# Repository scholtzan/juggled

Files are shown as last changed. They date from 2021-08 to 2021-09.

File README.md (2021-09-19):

# juggled - LED Juggling Ball

> Work in progress

This repository contains all the files and instructions for 3D printing and creating LED juggling balls that can be controlled via Bluetooth.

_Watch a demo of the juggling balls on Youtube:_

Youtube video (https://www.youtube.com/watch?v=KDMFEAo71LQ)

## Required Materials

The following components are required to build a single juggling ball:

* ESP32
 DEVKIT V1
	* This development board has an onboard Bluetooth module, will control the LEDs and collect data from the accelerometer
* Lithium 
Battery
 3.7V
	* The battery will power the ESP32 and all other components
* Li-lon Battery
 Charger
	* This component will ensure that the Lithium battery can be recharged via micro USB
* Accelerometer
	* For collecting data on whether the juggling ball has been thrown or caught
* 2x RGB LEDs
	* To make the juggling ball glow
* Resistors
	* 1x 1kΩ
	* 1x 4.7kΩ
	* Used to read the battery charge via the ESP32
* Switch
	* To turn the juggling ball on and off
* Capacitor (1 to 100uF)
	* Required in order to ensure ESP32 gets flashed without having to push any buttons on the microcontroller
* Wire
	* For connecting all the components
* Heat Shrink Tubes
	* For insulating soldered wires
* Soldering Iron + Solder
	* All the components need to be soldered together
* Transparent TPU
	* For printing the outer shell
	* Soft and flexible material will ensure that components and inner core are protected when juggling balls are dropped
* Clear PLA+
	* For inner core that will help to keep electronics in place
* Hot Glue
	* For glueing outer shell onto inner core and for fixating electronics

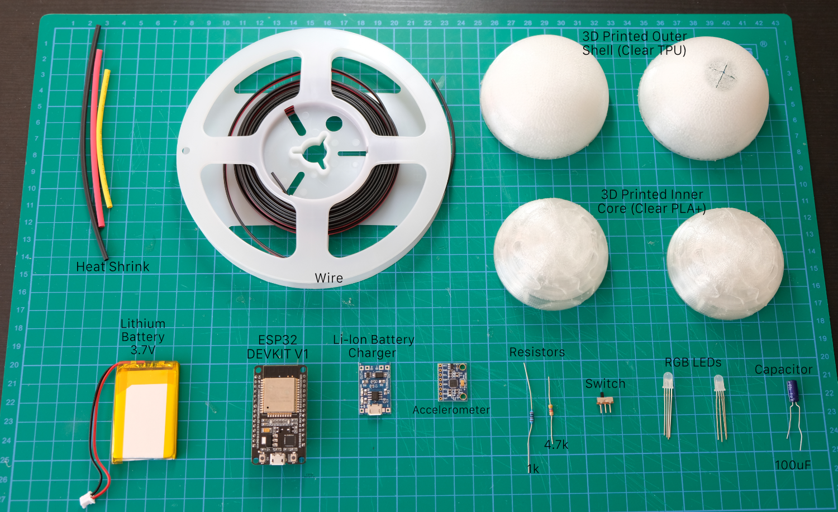
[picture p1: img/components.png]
Components


## 3D Printed Shell

The juggling ball consists of an inner core and an outer shell. The models can be found in the `models/` folder.
All files are also available on Thingiverse: https://www.thingiverse.com/thing:4969010

For printing the inner core which will hold all the components in place, use a transparent material. PLA+ or PETG are more sturdy, but PLA should also work. I have used the following parameters for printing the inner core with transparent PLA+:

* Temperature: 200C
* Build Plate Temperature: 60C
* Layer Height: 0.2mm
* Infill Density: 5%
* Infill Pattern: Gyroid
* Print Speed: 80mm/s
* Generate Support: yes
	* Support density: 5%

The inner core and all components are protected by an outer shell printed with transparent TPU. The outer shell consists of two parts - a back and a front. The front will allow access to the switch and USB ports. I have used the following parameters for printing the shell:

* Temperature: 220C
* Build Plate Temperature: 75C
* Layer Height: 0.2mm
	* Adaptive Layers: yes
		* Maximum Variation: 0.1mm
		* Variation Step Size: 0.1mm
* Flow: 105%
* Infill Density: 30%
* Infill Pattern: Gyroid
* Print Speed: 20mm/s
* Retraction Distance: 3mm
* Generate Support: no

## Circuit Overview

The following diagram shows how the circuit for the LED juggling ball works:

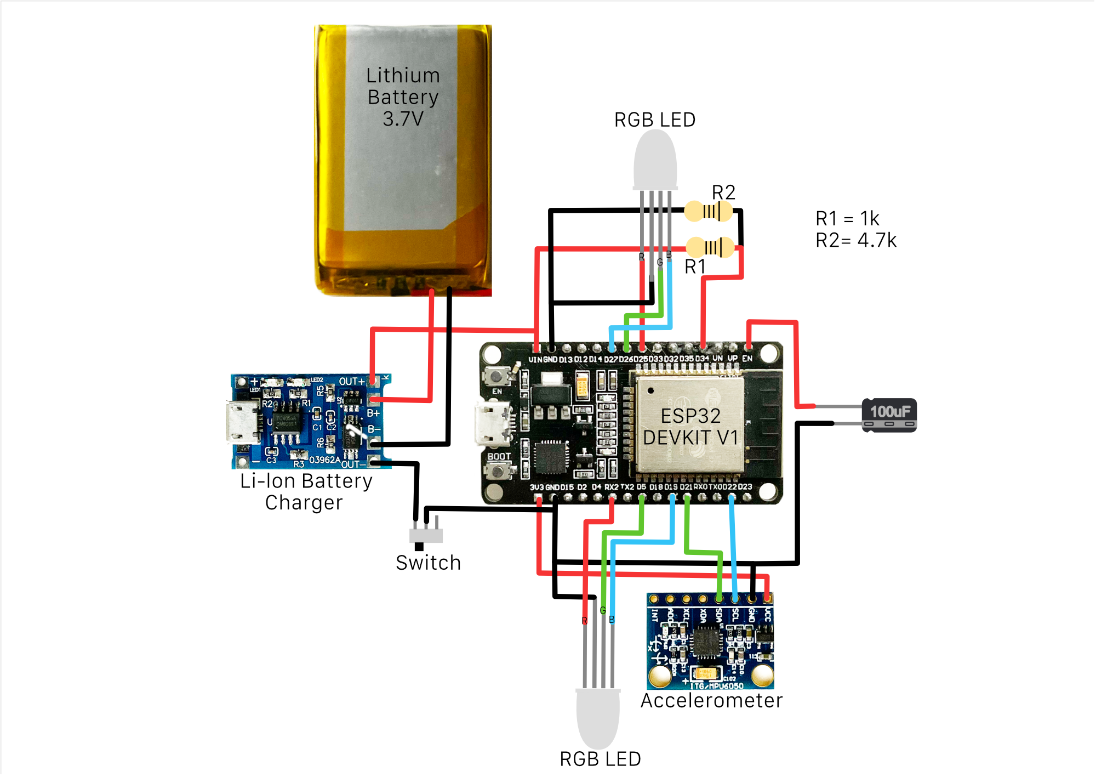
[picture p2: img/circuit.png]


1. The lithium battery outputs 3.7V when fully charged and can power the ESP32 DEVKIT
2. The lithium battery is connected to a charger module which allows the battery to be charged via micro USB
3. The two RGB LEDs are directly connected to the ESP32
4. The two resistors connect the lithium battery directly to one pin of the ESP32. This connection will be used to determine how much charge the battery has left
5. The accelerometer is connected to and powered by the ESP32
6. The capacitor is connected to EN to ensure the ESP32 gets flashed without having to press any buttons

## Assembly

For assembling and soldering the electronic components together, follow the circuit overview diagram above. As space is very limited inside the juggling ball, the components need to be sandwiched together:

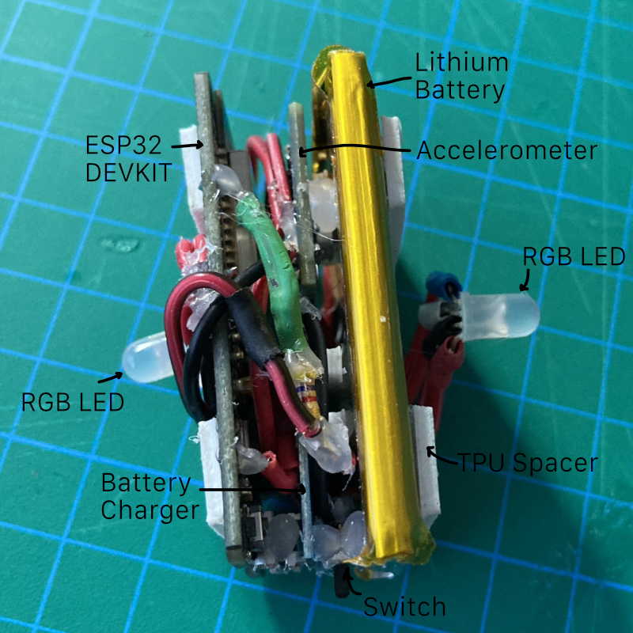
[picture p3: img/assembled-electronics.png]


The switch, battery charging module and accelerometer are put in between the lithium battery and ESP32 DEVKIT. The LEDs will be located on the battery and the ESP32. To ensure components stay in place, I printed some additional spacers using TPU and used some hot glue. The assembled bock of electronic components should not exceed 22mm in height as it would otherwise not fit into the inner core of the juggling ball. Ensure that the switch and the USB slots a properly aligned with the opening.

Once all the electronic components have been assembled, they can be place inside the inner core of the juggling ball. Each side of the inner core has holes for the LEDs to fit through. The two pieces for the inner core need to be glue together, either by using hot glue or Gorilla glue. Next, glue the two pieces of the outer shell onto the inner core using hot glue. Make sure that the piece of shell with the opening to access the switch and USB ports is properly aligned.

## Juggling Ball Software

The code running on the ESP32 of each juggling ball is located in the `ball-code` directory. The code can be [loaded on to the ESP32](https://www.etechnophiles.com/how-to-install-program-an-esp32-with-arduino-ide-for-the-first-time/) using [Arduino IDE](https://www.arduino.cc/en/software).

The code running on the juggling balls will allow devices to connect to it via BLE and send commands to change the color or get information about the battery voltage.

### Protocol

For specifying the LED behaviour the juggling ball can process messages that follow the following format:

```
set;<action>;<arg>|<action>;<arg>|...
```

The juggling ball behaviour can be defined in multiple steps. Each step is separated by `|`. For each step an `action` is specified, some `action`s require additional `arg`uments to be specified, such as `setcolor` expects the RGB values for the two LEDs. Once an action has been completed, the juggling ball will move on to process the next defined step. Once the last step defined have been processed, the juggling ball will again go back to the first step.

Supported `action`s are: `wait`, `thrown`, `caught` and `setcolor`. `arg` is required when `wait` and `setcolor` is used. For `wait` the millisecons how long the ball will wait until processing the next step needs to be specified. `setcolor` requires the `<r>,<g>,<b>;<r>,<g>,<b>` values of the two LEDs.

For setting the color of one LED to red and the other to blue the message would look as follows:

```
set;setcolor;255,0,0;0,0,255
```  

To have the juggling ball switch between red and green every second the message would look like:

```
set;wait;1000|setcolor;255,0,0;0,0,255|wait;1000|setcolor;0,0,255;0,0,255
```

To change the color to blue when a ball is in the air and to red when it is caught:

```
set;caught|setcolor;255,0,0;255,0,0|thrown|setcolor;0,0,255;0,0,255
```

All messages need to be converted to HEX. So for the first example the following message would need to be sent to the juggling ball in order for it to correctly interpret it: 

```
7365743b636f6c6f723b3b3235352c302c303b302c302c323535
```

## iOS Application

The code for the iOS application is in the `app/` directory, which makes connecting juggling balls, defining behaviours and collecting statistics very easy. The application is not part of the App Store, instead it can be loaded on to iOS devices via Xcode.

### Usage

New juggling balls can be connected to via the "+" button. A list of available juggling balls will appear, balls can get selected and will appear under "Home".

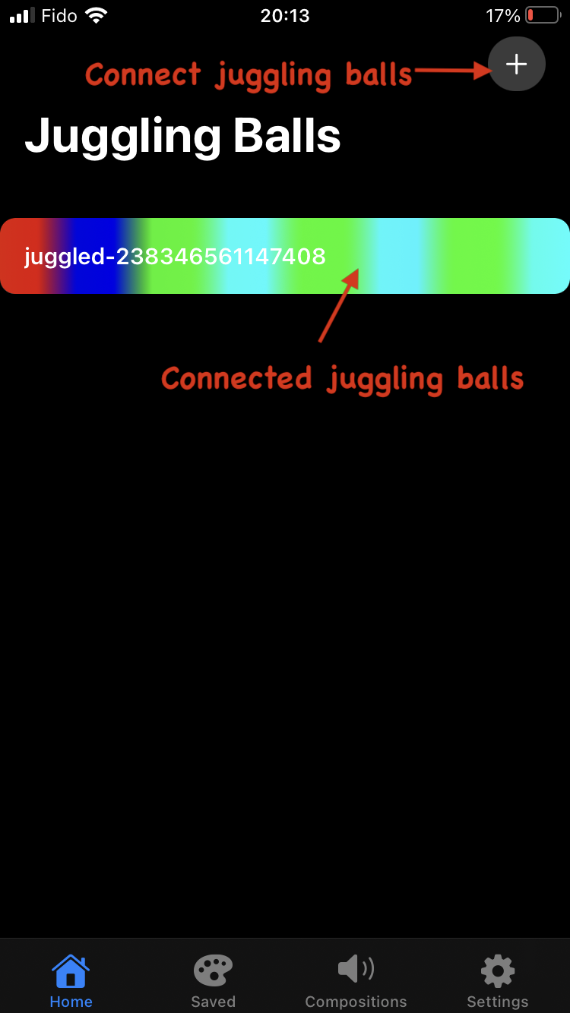
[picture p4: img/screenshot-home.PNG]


Clicking on a juggling ball entry will show the configuration of the juggling ball. The juggling ball routine can be edited by deleting steps or adding new steps via the "+ Add Step" button.

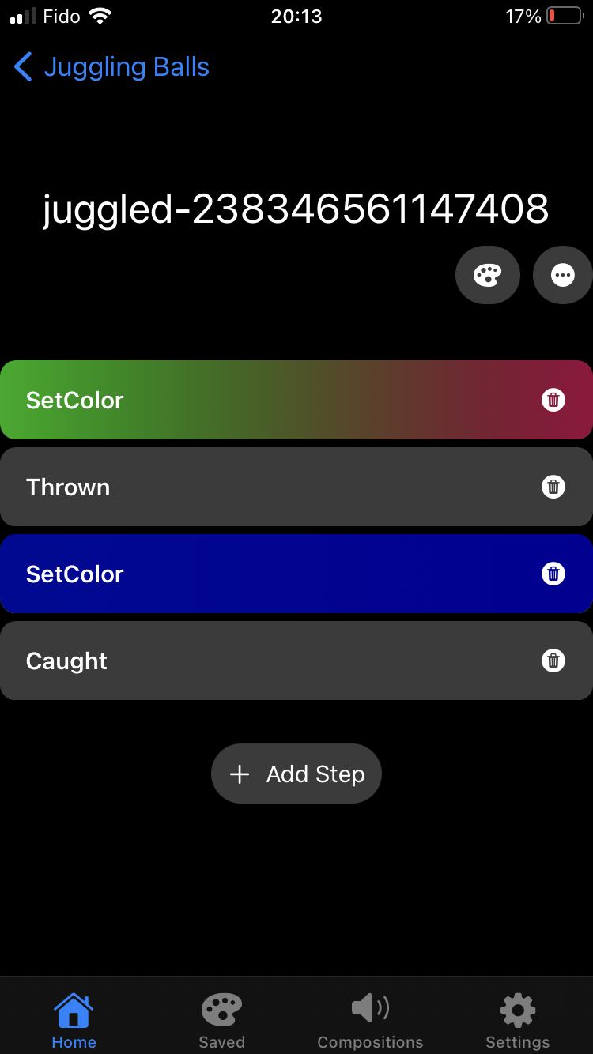
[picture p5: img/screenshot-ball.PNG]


When adding a new step, `Set Color` is selected by default. This action allows to set the color for each LED.

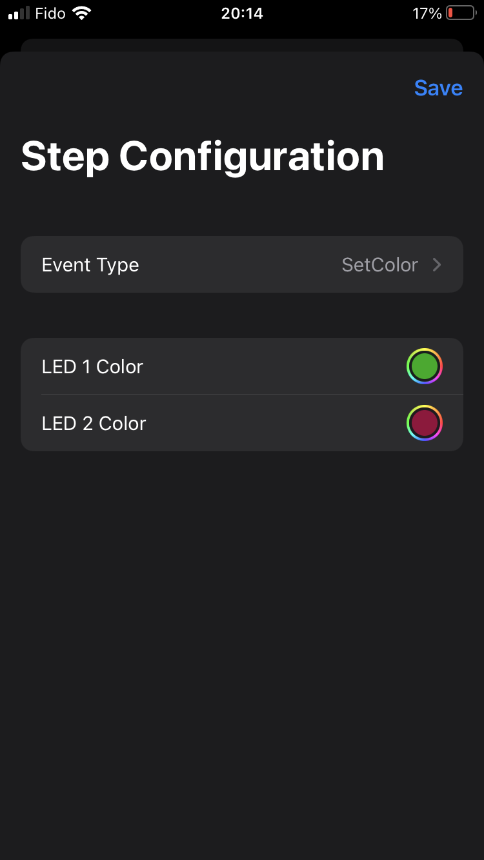
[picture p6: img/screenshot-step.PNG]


Other actions, such as `Caught`, `Thrown` and `Wait` can be selected by changing the "Event Type".

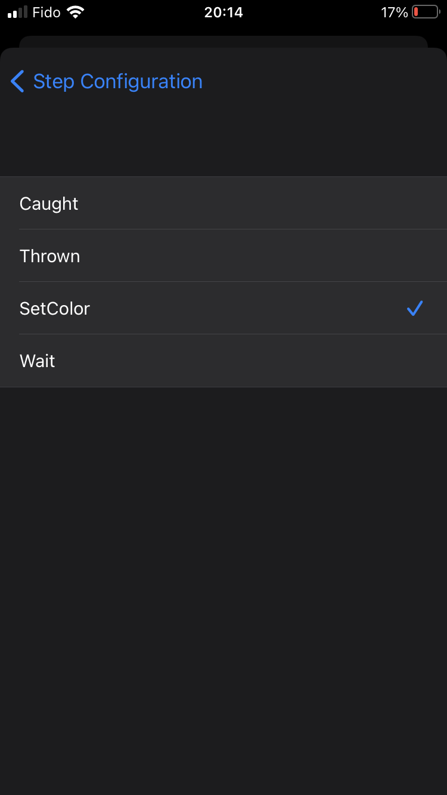
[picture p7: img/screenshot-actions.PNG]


It is also possible to save routines and apply them to other juggling balls later. All saved routines can be found in the "Saved" tab. Saved routines can also be deleted and edited.

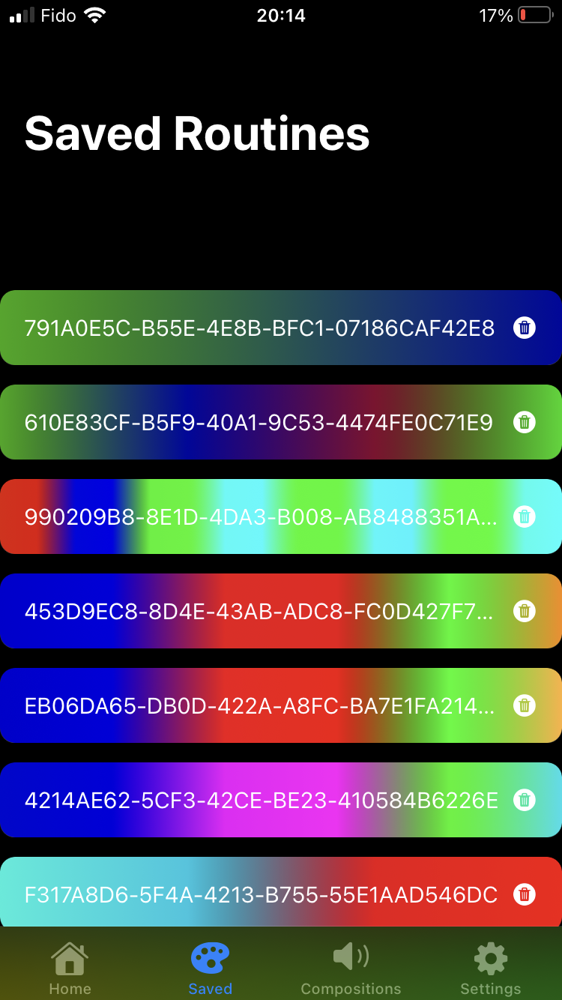
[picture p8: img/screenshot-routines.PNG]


To apply a saved routine to a juggling ball, press the button with the palette icon which will list all available routines.

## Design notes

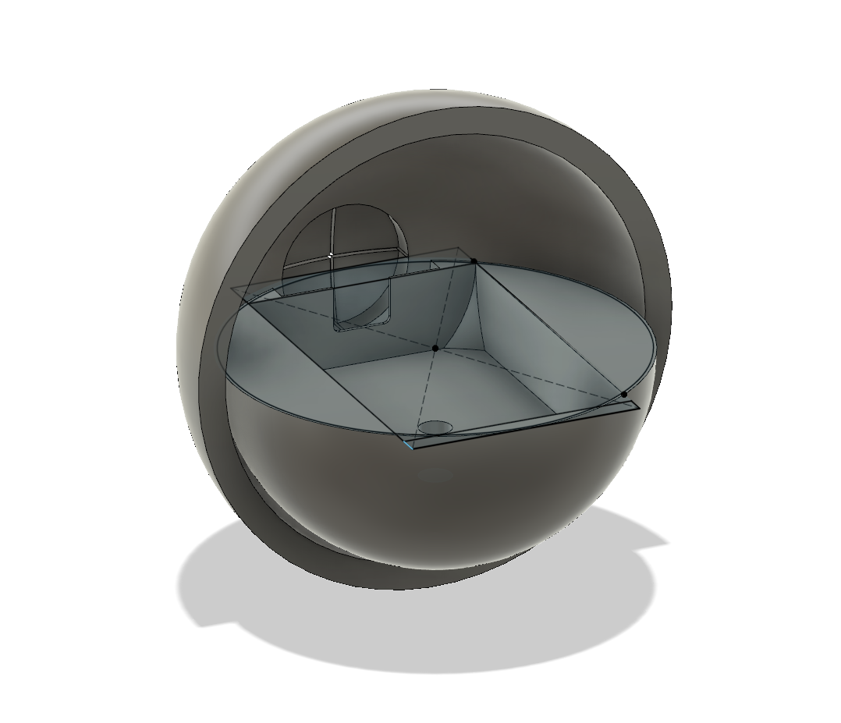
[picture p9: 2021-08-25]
model/juggling-ball-model-screenshot.png

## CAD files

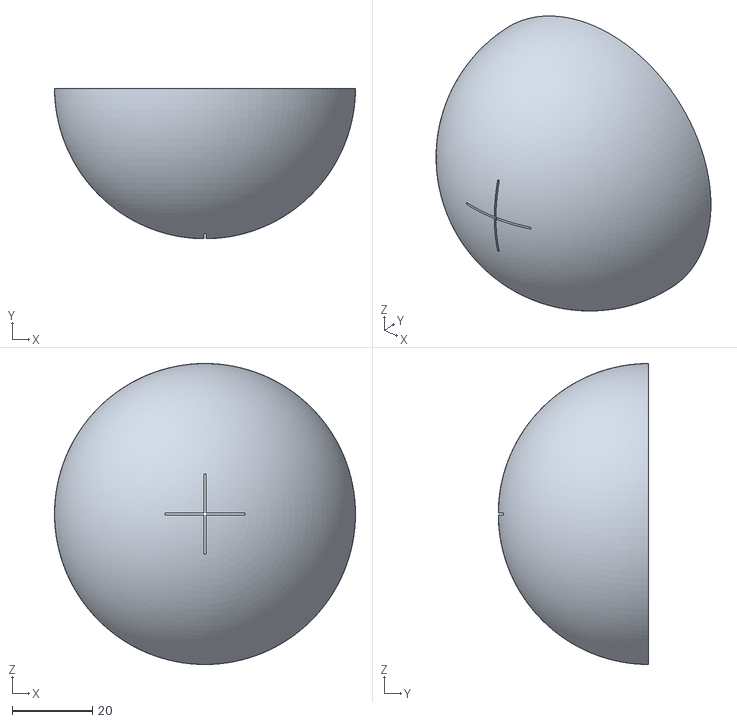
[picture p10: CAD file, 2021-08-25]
model/juggling-ball-shell-front.stl
75.0 x 37.5 x 75.0

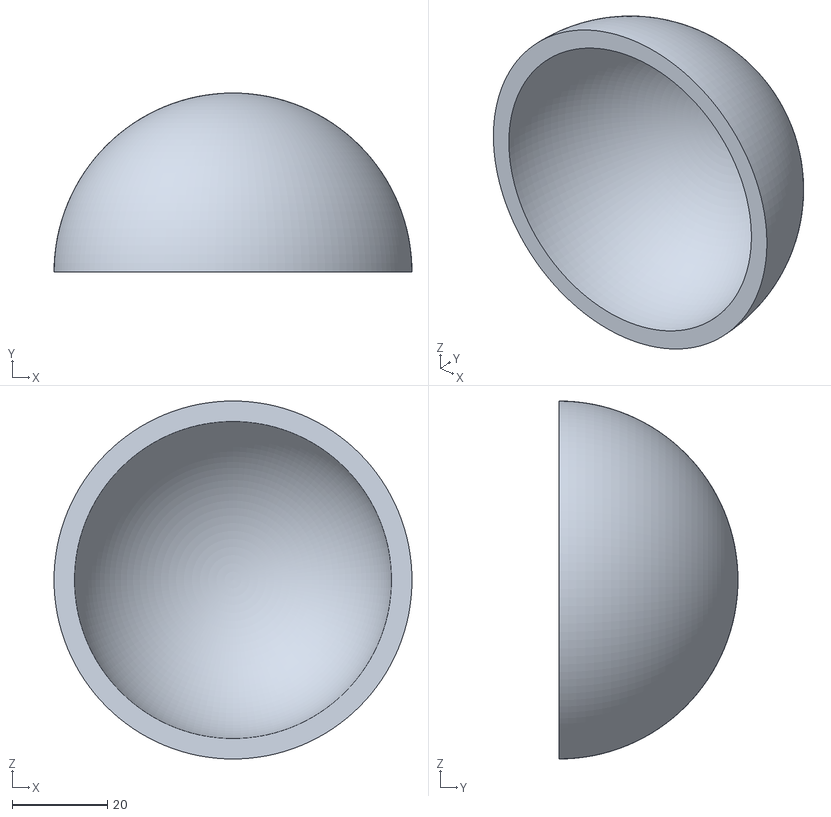
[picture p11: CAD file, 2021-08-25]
model/juggling-ball-shell-back.stl
75.0 x 37.5 x 75.0

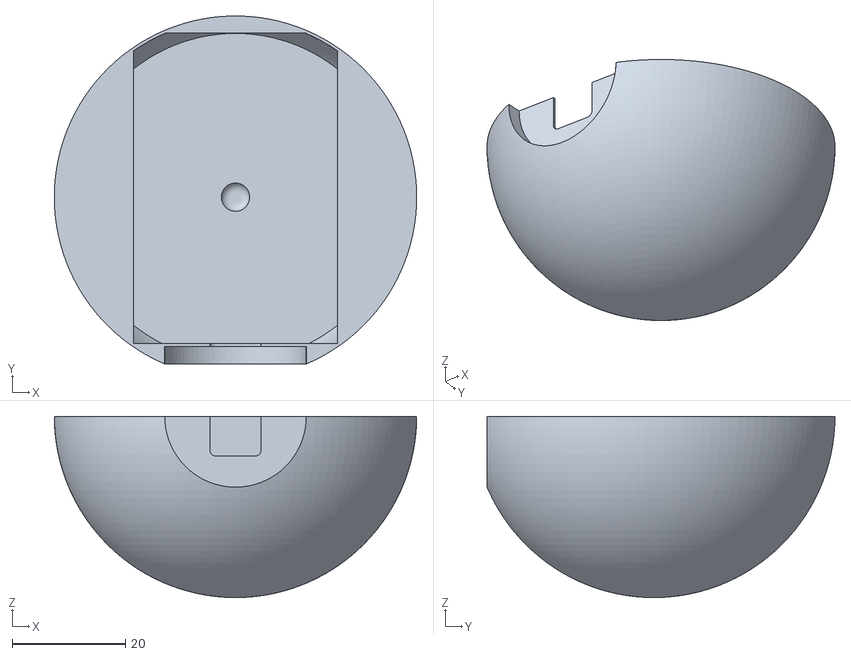
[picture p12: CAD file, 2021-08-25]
model/juggling-ball-inner.stl
64.0 x 61.4 x 32.0

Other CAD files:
model/led-juggling-ball.f3d

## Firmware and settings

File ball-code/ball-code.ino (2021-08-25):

#include <Adafruit_MPU6050.h>
#include <Adafruit_Sensor.h>
#include <Wire.h>
#include <BLEDevice.h>
#include <BLEUtils.h>
#include <BLEServer.h>
#include <string>
#include <cstdlib>
#include <math.h>
#include <queue>
#include "soc/soc.h"
#include "soc/rtc_cntl_reg.h"

using namespace std;

#define SERVICE_UUID        "4fafc201-1fb5-459e-8fcc-c5c9c331914b"
#define CHARACTERISTIC_UUID "beb5483e-36e1-4688-b7f5-ea07361b26a8"

Adafruit_MPU6050 mpu;

int red1 = 16;
int green1 = 5;
int blue1 = 19;

int red2 = 25;
int green2 = 26;
int blue2 = 27;

int batteryPin = 34;

int freq = 5000;
int resolution = 8;
int ledChannel[2][3] = {
  {0, 1, 2},
  {3, 4, 5}  
};

float prev_sm = 0.0;

class Color {
  public:
    int r;
    int g;
    int b;
    
    Color(int red, int green, int blue) {
      r = red;
      g = green;
      b = blue;
    }

    Color(string color) {
      int rgb[] = {0, 0, 0};
      int c = 0;
      int prev = 0;
      
      for (int i = 0; i < color.length(); i++) {
        if (color[i] == ',') {
          rgb[c] = atoi(color.substr(prev, i - prev).c_str());
          c += 1;
          prev = i + 1;
        }
      }

      rgb[c] = atoi(color.substr(prev, color.length() - prev).c_str());

      r = rgb[0];
      g = rgb[1];
      b = rgb[2];
    }

    int* to_array() {
      int arr[3] = {r, g, b};
      return arr;
    }
};

class Command {
  private:
    string event;
    string arg;
    Color color0;
    Color color1;

  public:
    Command(string e, string a, Color c0, Color c1): color0(0,0,0), color1(0,0,0) {
      event = e;
      arg = a;
      color0 = c0;
      color1 = c1;
    }

    string getEvent() {
      return event;  
    }

    string getArg() {
      return arg;  
    }

    Color getColor0() {
      return color0;  
    }

    Color getColor1() {
      return color1;  
    }
};

queue<Command> command_queue;

class MyCallbacks: public BLECharacteristicCallbacks {
    void onWrite(BLECharacteristic *pCharacteristic) {
      string value = pCharacteristic->getValue();
      bool parsing_done = false;

      if (value.length() > 0) {
        Serial.println("*********");
        Serial.print("New value: ");

        string action = value.substr(0, 3);
        value = value.substr(4, value.length() - 4);
        if (action == "get") {
          string val = value.substr(0, 3);
          if (val == "bat") {
            // battery
            int voltage = (int)(((analogRead(batteryPin)  * 3.3 ) / (4095)) * 100);
            pCharacteristic->setValue(voltage);
            parsing_done = true; 
          } else if (val == "tem") {
            // temperature  
            // todo
          }
        } else if (action == "set") {
          // clear queue
          queue<Command> empty;
          swap( command_queue, empty );
          
          while (!parsing_done) {
            string event = value.substr(0, value.find(";"));
            value = value.substr(value.find(";") + 1, value.length() - value.find(";") - 1);

            string arg = value.substr(0, value.find(";"));
            value = value.substr(value.find(";") + 1, value.length() - value.find(";") - 1);

            for (int i = 0; i < arg.length(); i++){
                Serial.print(arg[i]);
            }

            Color color0(value.substr(0, value.find(";")));

            value = value.substr(value.find(";") + 1, value.length() - value.find(";") - 1);

            int end;
            if (value.find("|") != -1) {
              end = value.find("|");
            } else {
              end = value.length();
            }
  
            Color color1(value.substr(0, end));

            if (end != value.length()) {
              value = value.substr(end + 1, value.length() - end - 1);
            }
  
            Command cmd(event, arg, color0, color1);
            command_queue.push(cmd);

            if (end == value.length()) {
              value = "";
              parsing_done = true;  
            }
          }
        }
      }
    }
};

void setup() {
   WRITE_PERI_REG(RTC_CNTL_BROWN_OUT_REG, 0); //disable brownout detector   

  ledcSetup(ledChannel[0][0], freq, resolution);
  ledcAttachPin(red1, ledChannel[0][0]);

  ledcSetup(ledChannel[0][2], freq, resolution);
  ledcAttachPin(blue1, ledChannel[0][2]);

  ledcSetup(ledChannel[0][1], freq, resolution);
  ledcAttachPin(green1, ledChannel[0][1]);
  
  ledcSetup(ledChannel[1][0], freq, resolution);
  ledcAttachPin(red2, ledChannel[1][0]);

  ledcSetup(ledChannel[1][2], freq, resolution);
  ledcAttachPin(blue2, ledChannel[1][2]);

  ledcSetup(ledChannel[1][1], freq, resolution);
  ledcAttachPin(green2, ledChannel[1][1]);

  Serial.begin(115200);

  if (!mpu.begin()) {
    Serial.println("Failed to find MPU6050 chip");
    while (1) {
      delay(10);
    }
  }
  Serial.println("MPU6050 Found!");
//
  mpu.setAccelerometerRange(MPU6050_RANGE_8_G);
  mpu.setGyroRange(MPU6050_RANGE_500_DEG);
  mpu.setFilterBandwidth(MPU6050_BAND_21_HZ);
//  
  BLEDevice::init("Juggling ball 1");
  BLEServer *pServer = BLEDevice::createServer();
  BLEService *pService = pServer->createService(SERVICE_UUID);
  BLECharacteristic *pCharacteristic = pService->createCharacteristic(
                                         CHARACTERISTIC_UUID,
                                         BLECharacteristic::PROPERTY_READ |
                                         BLECharacteristic::PROPERTY_WRITE
                                       );
  pCharacteristic->setValue("Hello World says Neil");
  pCharacteristic->setCallbacks(new MyCallbacks());
  pService->start();
  BLEAdvertising *pAdvertising = BLEDevice::getAdvertising();
  pAdvertising->addServiceUUID(SERVICE_UUID);
  pAdvertising->setScanResponse(true);
  pAdvertising->setMinPreferred(0x06);  // functions that help with iPhone connections issue
  pAdvertising->setMinPreferred(0x12);
  BLEDevice::startAdvertising();
//  Serial.println("Characteristic defined! Now you can read it in your phone!");                              
//  BLEServer *pServer = BLEDevice::createServer();
//
//  BLEService *pService = pServer->createService(SERVICE_UUID);
//
//  BLECharacteristic *pCharacteristic = pService->createCharacteristic(
//                                         CHARACTERISTIC_UUID,
//                                         BLECharacteristic::PROPERTY_READ |
//                                         BLECharacteristic::PROPERTY_WRITE
//                                       );
//
//  pCharacteristic->setValue("Hello world");
//  pCharacteristic->setCallbacks(new MyCallbacks());
//  pService->start();
//
//  BLEAdvertising *pAdvertising = pServer->getAdvertising();
//  pAdvertising->addServiceUUID(SERVICE_UUID);
//  pAdvertising->setScanResponse(true);
//  pAdvertising->setMinPreferred(0x06);  // functions that help with iPhone connections issue
//  pAdvertising->setMinPreferred(0x12);
//  pAdvertising->start();

  delay(500);
  
  WRITE_PERI_REG(RTC_CNTL_BROWN_OUT_REG, 1); //enable brownout detector
}

void loop() {
  sensors_event_t a, g, temp;
  mpu.getEvent(&a, &g, &temp);
  float x = a.acceleration.x;
  float y = a.acceleration.y;
  float z = a.acceleration.z;

  float cur_sm = sqrt(x * x + y * y + z * z);

  if (!command_queue.empty()) {
    Command cmd = command_queue.front();
  
    if (cmd.getEvent() == "*") {
      ledcWrite(ledChannel[0][0], cmd.getColor0().r);
      ledcWrite(ledChannel[0][1], cmd.getColor0().g);
      ledcWrite(ledChannel[0][2], cmd.getColor0().b);
  
      ledcWrite(ledChannel[1][0], cmd.getColor1().r);
      ledcWrite(ledChannel[1][1], cmd.getColor1().g);
      ledcWrite(ledChannel[1][2], cmd.getColor1().b);
    } else if (cmd.getEvent() == "timed") {
      int millisec = atoi(cmd.getArg().c_str());
      ledcWrite(ledChannel[0][0], cmd.getColor0().r);
      ledcWrite(ledChannel[0][1], cmd.getColor0().g);
      ledcWrite(ledChannel[0][2], cmd.getColor0().b);
  
      ledcWrite(ledChannel[1][0], cmd.getColor1().r);
      ledcWrite(ledChannel[1][1], cmd.getColor1().g);
      ledcWrite(ledChannel[1][2], cmd.getColor1().b);
      delay(millisec);
      command_queue.pop();
      command_queue.push(cmd);
    } else if (cmd.getEvent() == "caught") {
      if (prev_sm < 2.5 && cur_sm > 2.5) {
        ledcWrite(ledChannel[0][0], cmd.getColor0().r);
        ledcWrite(ledChannel[0][1], cmd.getColor0().g);
        ledcWrite(ledChannel[0][2], cmd.getColor0().b);
    
        ledcWrite(ledChannel[1][0], cmd.getColor1().r);
        ledcWrite(ledChannel[1][1], cmd.getColor1().g);
        ledcWrite(ledChannel[1][2], cmd.getColor1().b);
        command_queue.pop();
        command_queue.push(cmd);
      }
    } else if (cmd.getEvent() == "thrown") {
      if (cur_sm < 2.5 && prev_sm > 2.5) {
        ledcWrite(ledChannel[0][0], cmd.getColor0().r);
        ledcWrite(ledChannel[0][1], cmd.getColor0().g);
        ledcWrite(ledChannel[0][2], cmd.getColor0().b);
    
        ledcWrite(ledChannel[1][0], cmd.getColor1().r);
        ledcWrite(ledChannel[1][1], cmd.getColor1().g);
        ledcWrite(ledChannel[1][2], cmd.getColor1().b);
        command_queue.pop();
        command_queue.push(cmd);
      }
    }
  }

  prev_sm = cur_sm;
  
  delay(50);
}

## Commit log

2021-08-15 List and connect to BLE devices
2021-08-16 Add circuit diagram
2021-08-25 Update circuit diagram
2021-08-25 Add juggling ball model
    [juggling-ball-inner.stl, juggling-ball-shell-back.stl, juggling-ball-shell-front.stl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]
2021-08-25 Add 3D printing notes
2021-08-25 Circuit overview
2021-08-25 Resize circuit image
2021-08-25 Electronics assembly
2021-08-25 Shell assembly
2021-09-17 Only list unconnected devices
